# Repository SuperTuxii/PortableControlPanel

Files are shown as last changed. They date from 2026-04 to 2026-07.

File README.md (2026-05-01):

# PortableControlPanel
A control panel with a touchscreen, speaker and more that magnetically connects to a stand. The builtin battery allows it to be taken around and used wirelessly. Placing it on the stand will charge the battery through the magnetic connectors. It can be used to control lights or as a macro pad etc.

I made this since my light switch is quite far from my bed and it's always annoying when I'm in bed and have to turn off the lights. So I will probably put this in my bed for that purpose, but making it wireless still leaves me with the possibility to use it in even more ways in the future.

# Images
## Panel
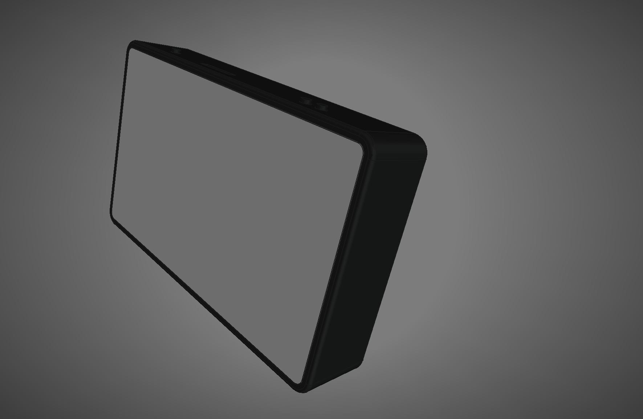
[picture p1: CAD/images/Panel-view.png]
View of the panel in CAD from the front

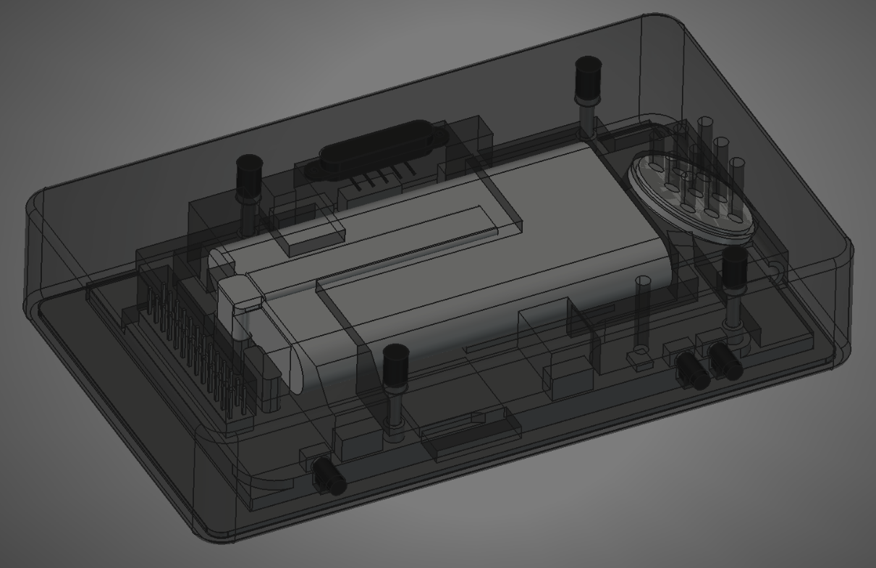
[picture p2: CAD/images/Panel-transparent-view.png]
View of the panel in CAD from the back with a transparent case

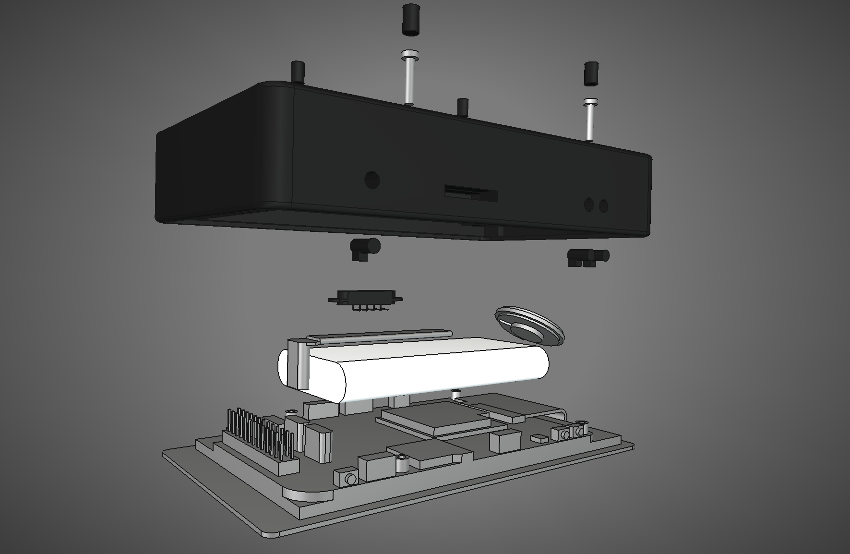
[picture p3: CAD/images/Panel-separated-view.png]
View of the separated panel in CAD

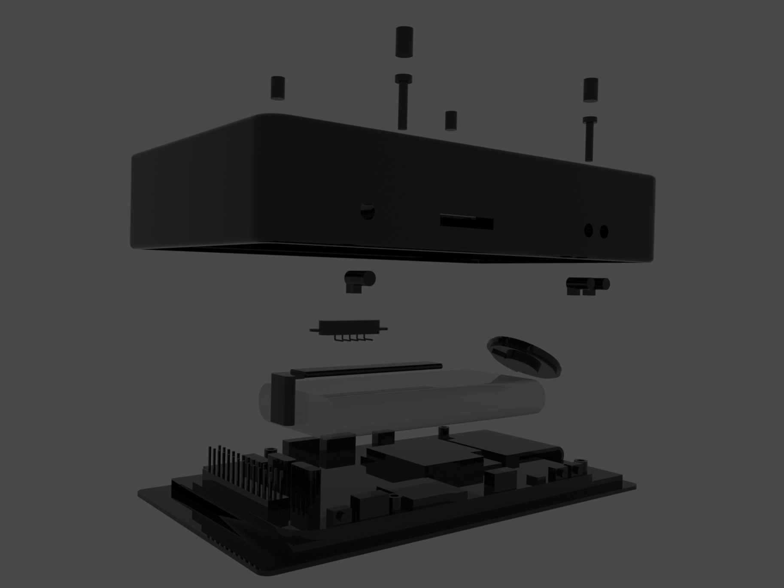
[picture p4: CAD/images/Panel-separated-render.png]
View of the separated panel as a render

## Stand
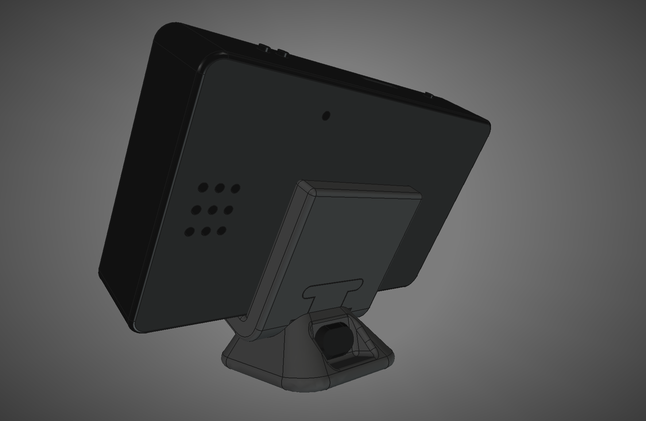
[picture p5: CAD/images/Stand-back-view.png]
View of the stand in CAD from the back

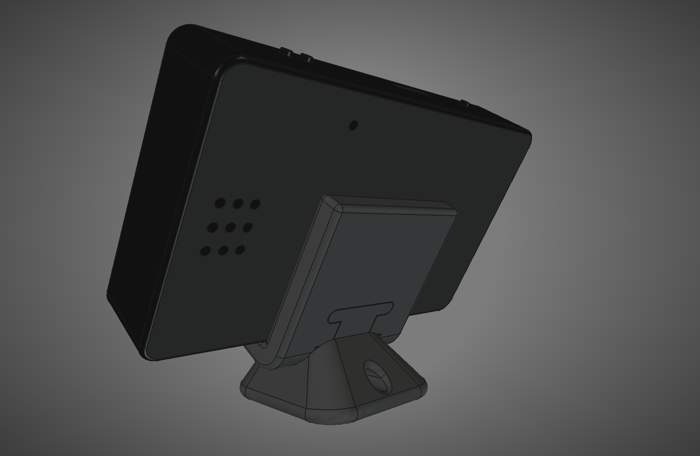
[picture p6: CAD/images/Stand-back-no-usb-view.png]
View of the stand without the usb port in CAD from the back

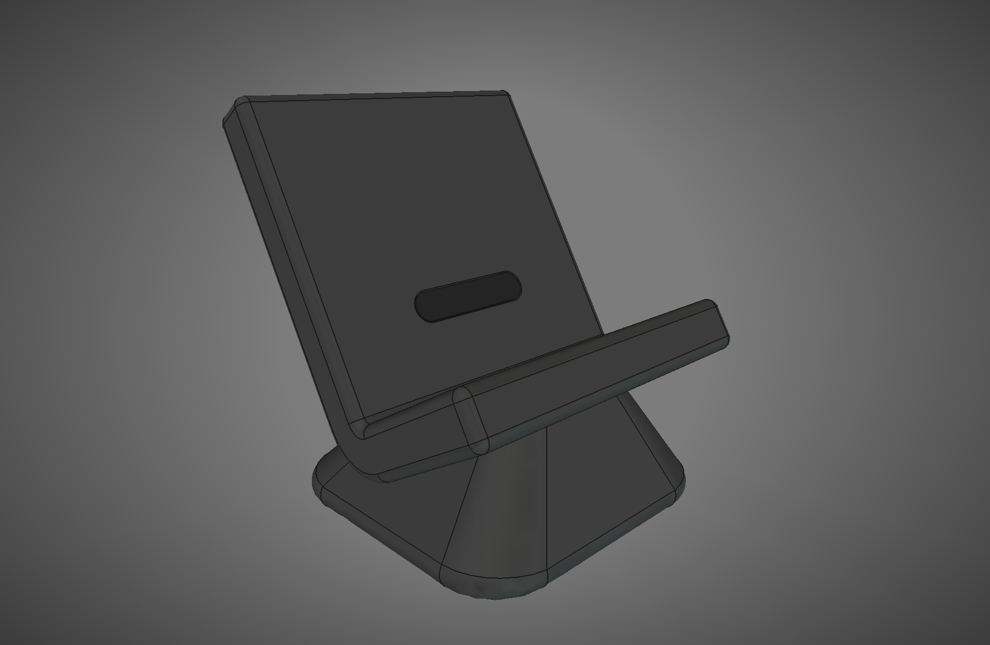
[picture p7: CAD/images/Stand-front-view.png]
View of the stand in CAD from the front

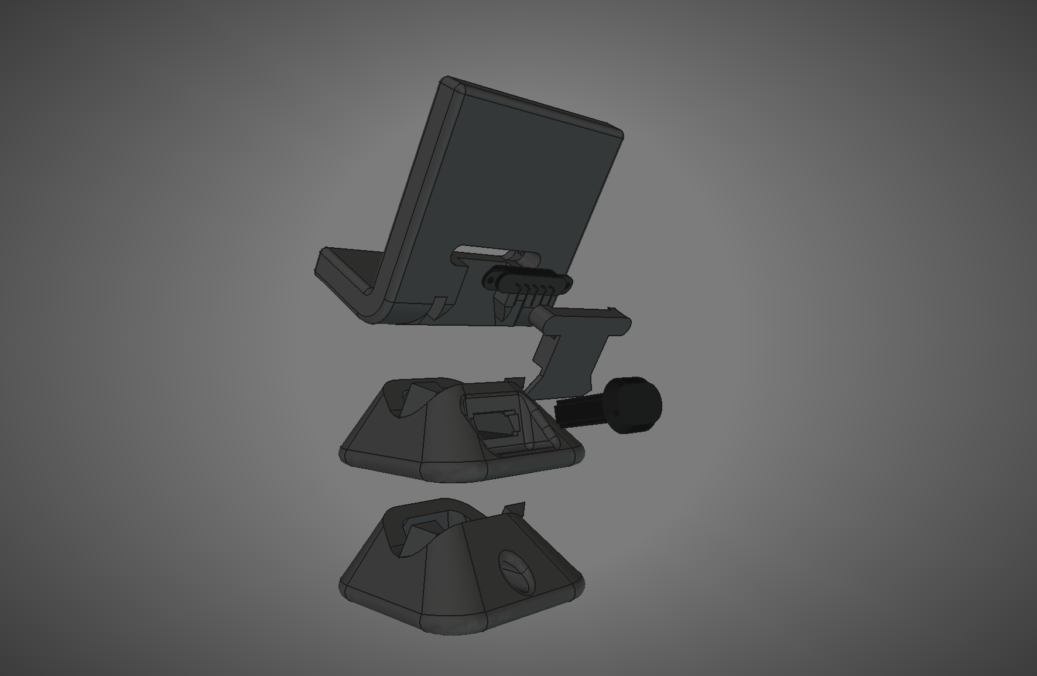
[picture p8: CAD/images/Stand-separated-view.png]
View of the separated stand in CAD


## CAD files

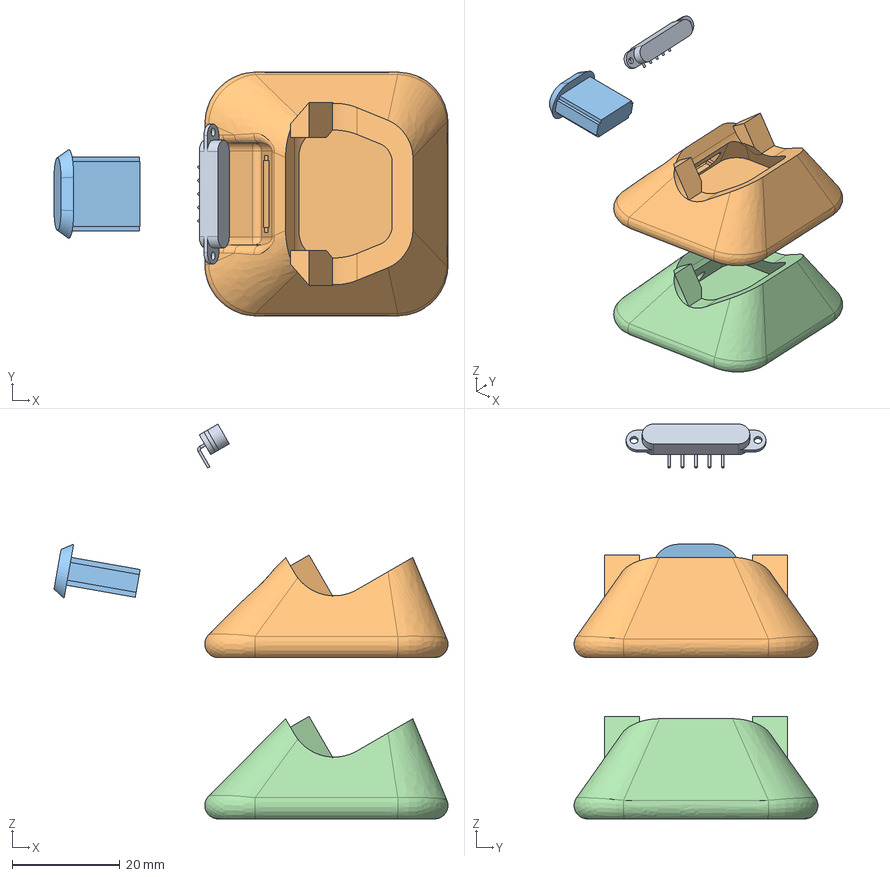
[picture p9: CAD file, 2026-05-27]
CAD/Stand-separated.FCStd
73.3 x 45.3 x 73.4 mm
MagnetConnector001
Base
UsbPort
BaseNoUsb

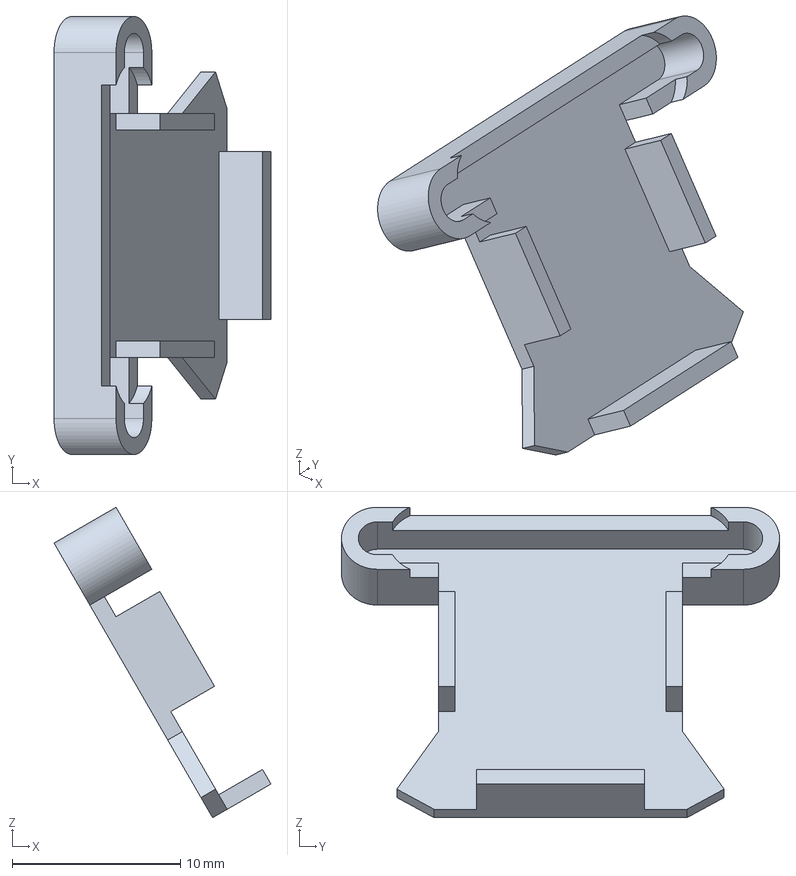
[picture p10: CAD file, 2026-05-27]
CAD/step_files/Stand-StandCover.step
12.9 x 26.0 x 18.4 mm

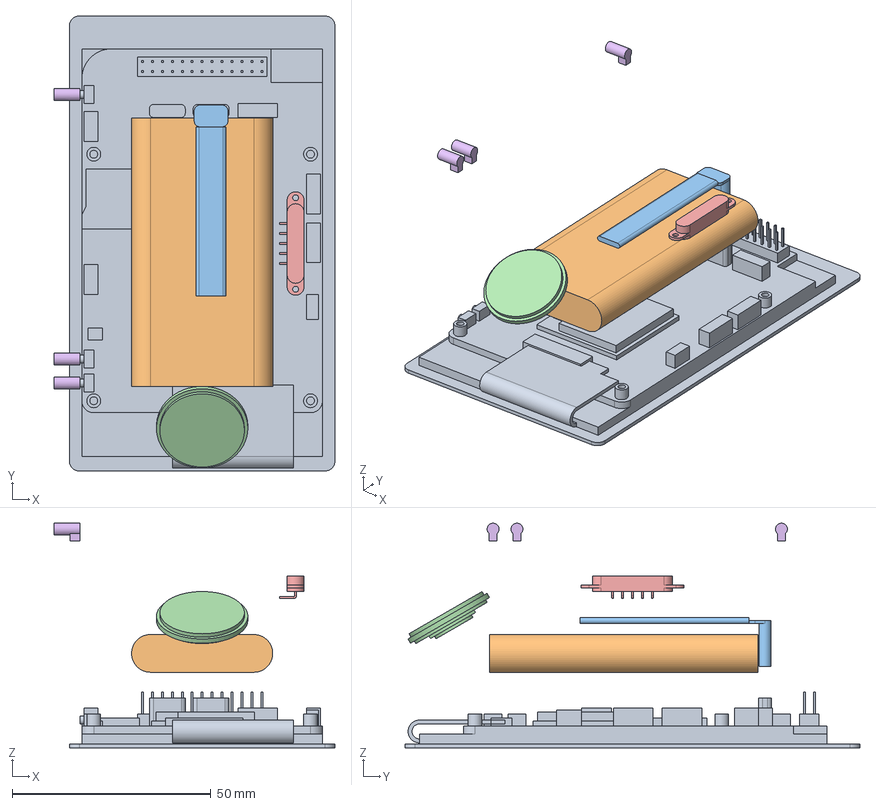
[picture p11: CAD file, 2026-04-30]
CAD/Panel-separated.FCStd
70.7 x 114.4 x 56.5 mm
DisplayModuleDevKit
Battery
UsbConnector
Speaker
MagnetConnector
ButtonPins

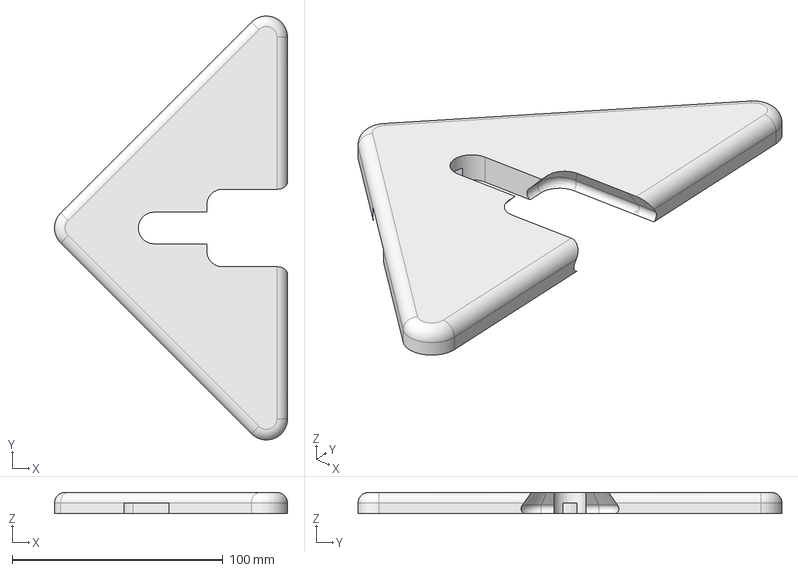
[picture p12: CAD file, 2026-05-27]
CAD/step_files/Stand-CornerBase.step
110.5 x 201.1 x 10.0 mm

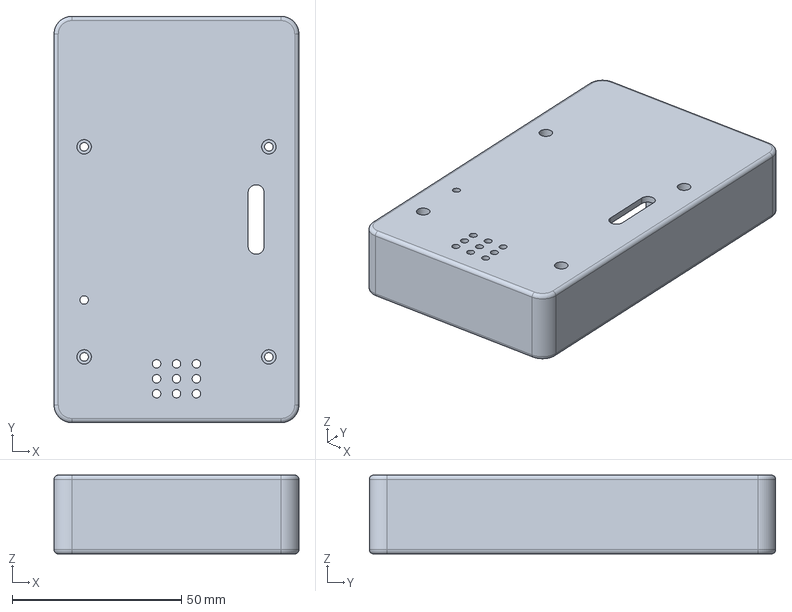
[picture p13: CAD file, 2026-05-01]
CAD/step_files/Panel-Case.step
72.3 x 119.9 x 23.2 mm

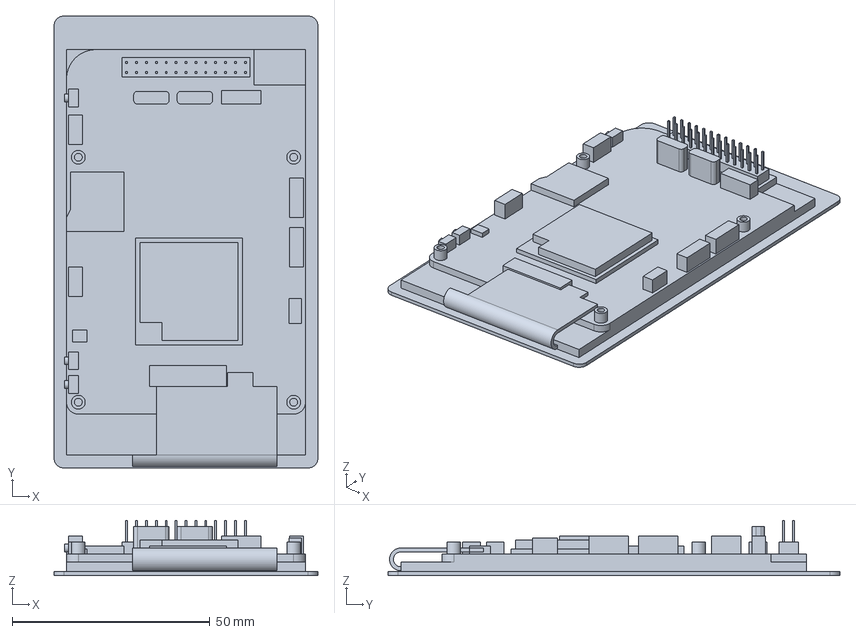
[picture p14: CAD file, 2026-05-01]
CAD/step_files/Panel-DisplayModuleDevKit.step
66.8 x 114.4 x 14.0 mm

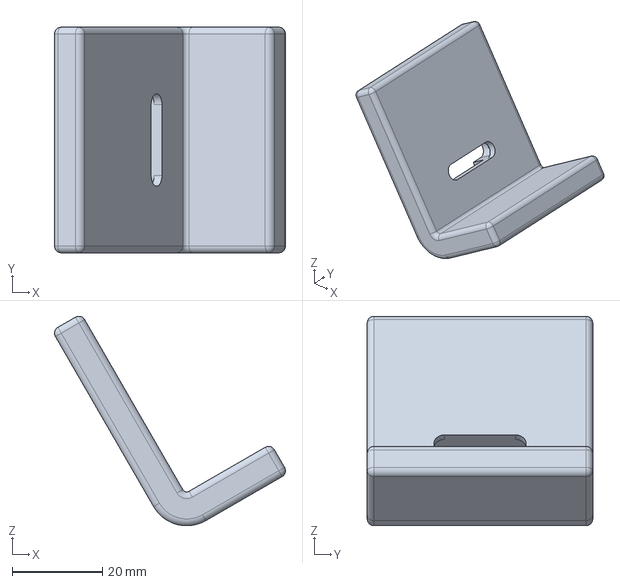
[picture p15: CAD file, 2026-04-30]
CAD/step_files/Stand-Stand.step
51.2 x 50.0 x 46.4 mm

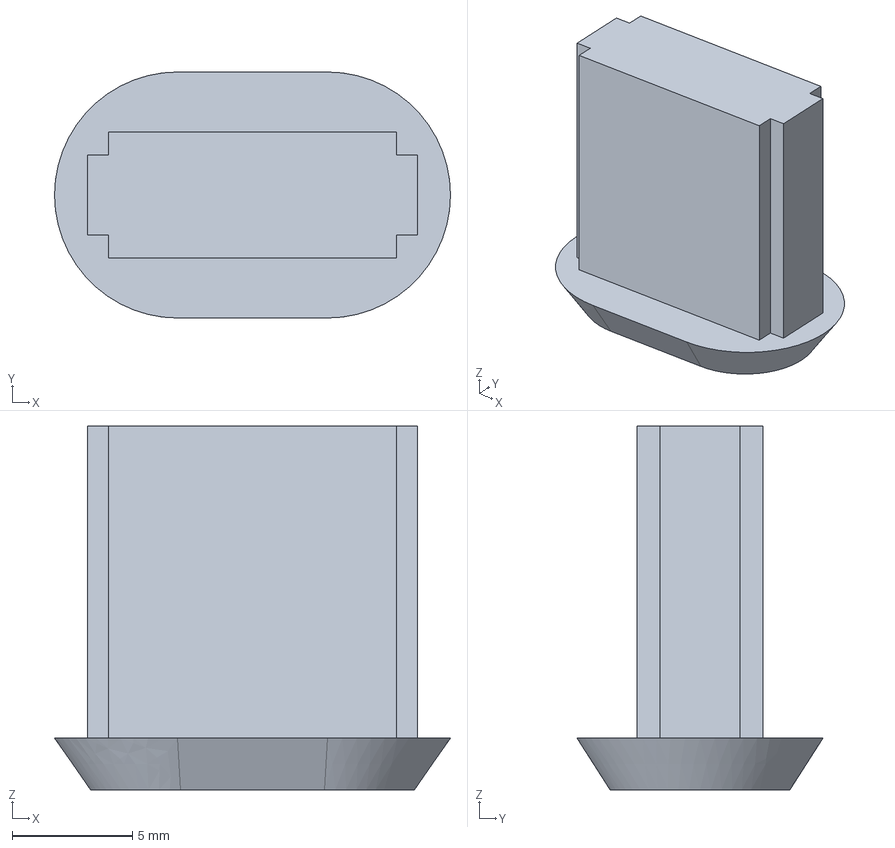
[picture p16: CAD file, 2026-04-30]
CAD/step_files/Stand-UsbPort.step
16.5 x 10.2 x 15.2 mm

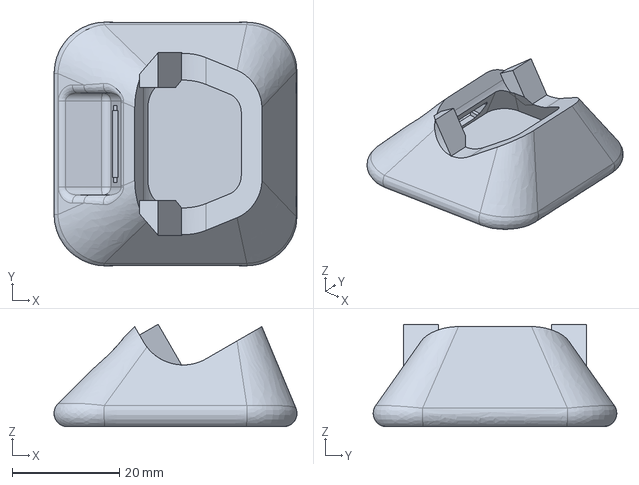
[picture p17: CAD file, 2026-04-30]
CAD/step_files/Stand-Base.step
45.2 x 45.3 x 19.1 mm

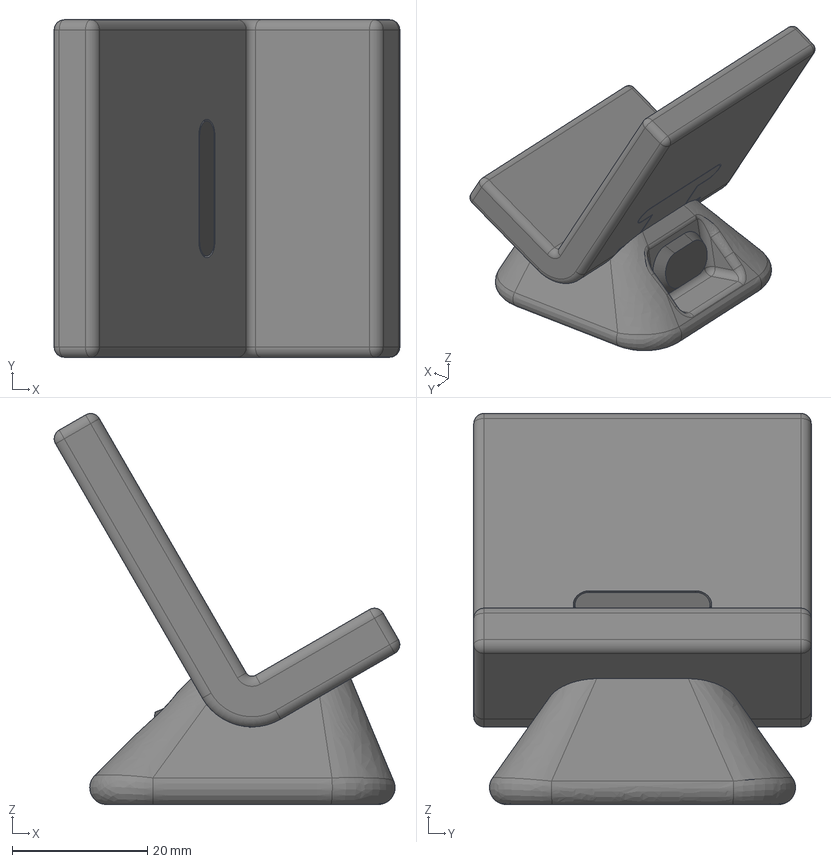
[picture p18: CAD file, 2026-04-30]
CAD/step_files/Stand.step
51.2 x 50.0 x 57.9 mm
Stand
Base
MagnetConnector001
UsbPort
StandCover

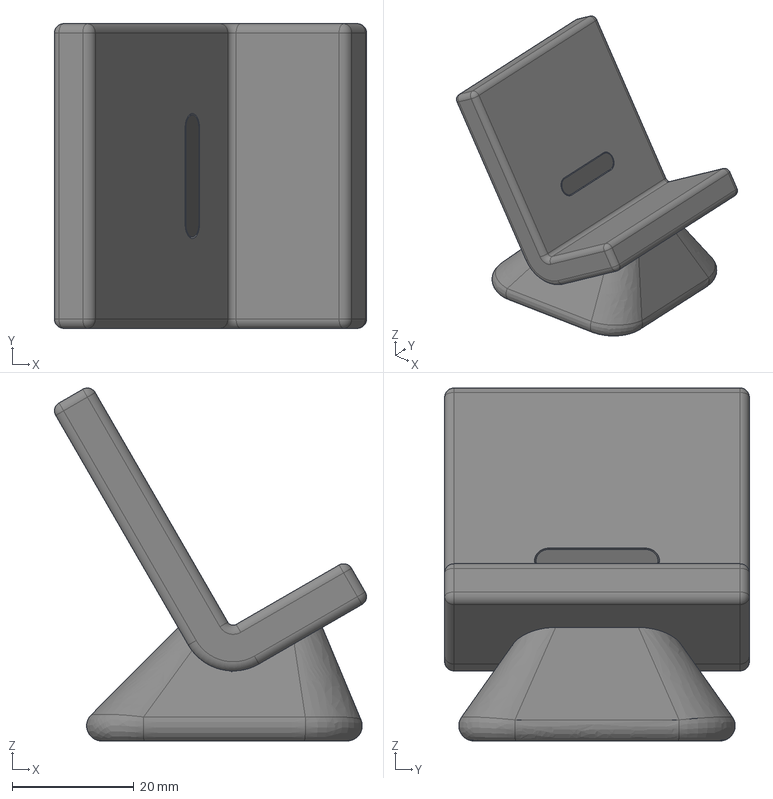
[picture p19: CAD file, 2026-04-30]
CAD/step_files/StandNoUsb.step
51.2 x 50.0 x 57.9 mm
Stand
MagnetConnector001
StandCover
BaseNoUsb

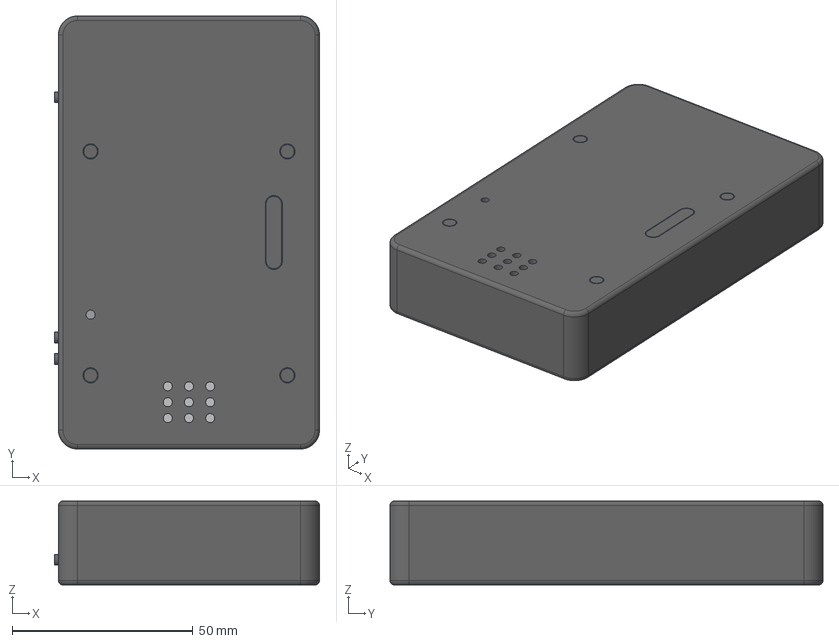
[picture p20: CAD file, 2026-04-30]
CAD/step_files/Panel.step
73.4 x 119.9 x 23.2 mm
ScrewCovers
Screws
ButtonPins
Case
MagnetConnector
Speaker
UsbConnector
Battery
DisplayModuleDevKit

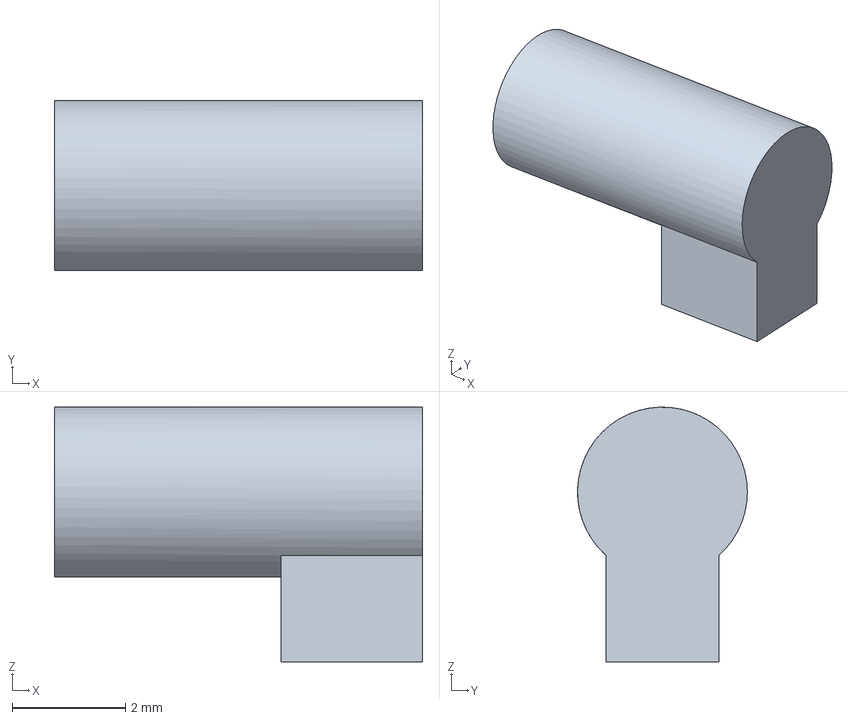
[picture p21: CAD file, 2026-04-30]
CAD/step_files/Panel-ButtonPin.step
6.50 x 3.00 x 4.50 mm

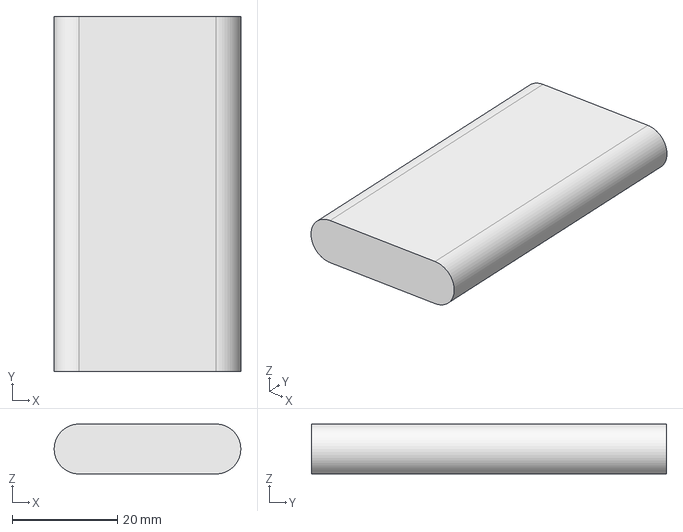
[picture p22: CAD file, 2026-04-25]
CAD/step_files/Panel-Battery.step
35.5 x 67.5 x 9.50 mm

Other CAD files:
CAD/step_files/Stand-BaseNoUsb.step
CAD/step_files/Panel-MagnetConnector.step
CAD/step_files/Panel-Speaker.step
CAD/step_files/Panel-UsbConnector.step
CAD/3d_printing/Panel-ButtonPin.3mf
CAD/3d_printing/Panel-Case.3mf
CAD/3d_printing/Panel-ScrewCover.3mf
CAD/3d_printing/Stand-Base.3mf
CAD/3d_printing/Stand-BaseNoUsb.3mf
CAD/3d_printing/Stand-CornerBase.3mf
CAD/3d_printing/Stand-Stand.3mf
CAD/3d_printing/Stand-StandCover.3mf
CAD/Panel.FCStd
CAD/Stand.FCStd
CAD/step_files/Panel-Screw.step
CAD/step_files/Panel-ScrewCover.step

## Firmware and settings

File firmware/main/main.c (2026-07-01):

/*
 * SPDX-FileCopyrightText: 2010-2022 Espressif Systems (Shanghai) CO LTD
 *
 * SPDX-License-Identifier: CC0-1.0
 */

#include <stdio.h>
#include <inttypes.h>

#include "sdkconfig.h"

#include "esp_log.h"
#include "tinyusb.h"
#include "tinyusb_default_config.h"
#include "tinyusb_cdc_acm.h"
#include "esp_lvgl_port.h"
#include "lvgl.h"
#include "lv_control_grid.h"
#include "display_driver.h"
#include "protocol.h"
#include "tinyusb_console.h"

#define ALIGN_UP(num, align)    (((num) + ((align) - 1)) & ~((align) - 1))
#define ALIGN_DOWN(num, align)  ((num) & ~((align) - 1))

static char *LVGL_TAG = "lvgl";

static esp_err_t lvgl_init() {
    ESP_LOGI(LVGL_TAG, "Initialize LVGL port");
    const lvgl_port_cfg_t lvgl_cfg = {
        .task_priority = LVGL_TASK_PRIORITY,
        .task_stack = LVGL_TASK_STACK_SIZE,
        .task_affinity = -1,
        .task_max_sleep_ms = LVGL_TASK_MAX_DELAY_MS,
        .task_stack_caps = MALLOC_CAP_SPIRAM,
        .timer_period_ms = LVGL_TICK_PERIOD_MS
    };
    ESP_ERROR_CHECK(lvgl_port_init(&lvgl_cfg));

    ESP_LOGI(LVGL_TAG, "Add MIPI DSI display");
    const lvgl_port_display_cfg_t display_cfg = {
        .io_handle = display_get_mipi_dpi_io(),
        .panel_handle = display_get_panel_handle(),
        .buffer_size = LCD_H_RES * LCD_V_RES,
        .double_buffer = true,
        .hres = LCD_H_RES,
        .vres = LCD_V_RES,
        .monochrome = false,
        .color_format = LV_COLOR_FORMAT_RGB565,
        .rotation = {
            .swap_xy = false,
            .mirror_x = false,
            .mirror_y = false,
        },
        .flags = {
            .buff_dma = true,
            .buff_spiram = true,
            .sw_rotate = true,
            .swap_bytes = false,
        }
    };
    const lvgl_port_display_dsi_cfg_t display_dsi_cfg = {
        //.flags.avoid_tearing = true   doesn't work for some reason. Me not know
    };
    lv_disp_t *display = lvgl_port_add_disp_dsi(&display_cfg, &display_dsi_cfg);
    lv_display_set_rotation(display, LV_DISPLAY_ROTATION_270);

    ESP_LOGI(LVGL_TAG, "Add touch");
    const lvgl_port_touch_cfg_t touch_cfg = {
        .disp = display,
        .handle = touch_get_tp_handle(),
    };
    lv_indev_t* touch_handle = lvgl_port_add_touch(&touch_cfg);

    ESP_LOGI(LVGL_TAG, "Aquire lvgl port lock");
    if (lvgl_port_lock(0)) {
        ESP_LOGI(LVGL_TAG, "Add LVGL widgets");
        lv_obj_set_style_bg_color(lv_screen_active(), lv_color_hex(0x000000), LV_PART_MAIN);
        lv_control_grid_create(lv_screen_active());
        lvgl_port_unlock();
    }
    return ESP_OK;
}

static void tinyusb_cdc_rx_callback(int itf, cdcacm_event_t *event) {
    if (itf != TINYUSB_PROTOCOL_PORT)
        return;
    tinyusbReadReady();
}

static esp_err_t tinyusb_init() {
    const tinyusb_config_t tusb_cfg = TINYUSB_DEFAULT_CONFIG();

    ESP_ERROR_CHECK(tinyusb_driver_install(&tusb_cfg));

    tinyusb_config_cdcacm_t acm_cfg = {
        .cdc_port = TINYUSB_PROTOCOL_PORT,
        .callback_rx = &tinyusb_cdc_rx_callback,
        .callback_rx_wanted_char = NULL,
        .callback_line_state_changed = NULL,
        .callback_line_coding_changed = NULL
    };
    ESP_ERROR_CHECK(tinyusb_cdcacm_init(&acm_cfg));
    ESP_ERROR_CHECK(tinyusb_console_init(TINYUSB_CDC_ACM_0));
    return ESP_OK;
}

void app_main(void) {
    // Initialize display and LVGL
    ESP_ERROR_CHECK(display_brightness_init());
    ESP_ERROR_CHECK(display_backlight_on());
    ESP_ERROR_CHECK(display_init());
    ESP_ERROR_CHECK(touch_init());
    ESP_ERROR_CHECK(lvgl_init());
    // Initialize TinyUSB (route console output to high speed usb)
    ESP_ERROR_CHECK(tinyusb_init());

    // printf("Hello world!\n");
    //
    // /* Print chip information */
    // esp_chip_info_t chip_info;
    // uint32_t flash_size;
    // esp_chip_info(&chip_info);
    // printf("This is %s chip with %d CPU core(s), %s%s%s%s, ",
    //        CONFIG_IDF_TARGET,
    //        chip_info.cores,
    //        (chip_info.features & CHIP_FEATURE_WIFI_BGN) ? "WiFi/" : "",
    //        (chip_info.features & CHIP_FEATURE_BT) ? "BT" : "",
    //        (chip_info.features & CHIP_FEATURE_BLE) ? "BLE" : "",
    //        (chip_info.features & CHIP_FEATURE_IEEE802154) ? ", 802.15.4 (Zigbee/Thread)" : "");
    //
    // unsigned major_rev = chip_info.revision / 100;
    // unsigned minor_rev = chip_info.revision % 100;
    // printf("silicon revision v%d.%d, ", major_rev, minor_rev);
    // if(esp_flash_get_size(NULL, &flash_size) != ESP_OK) {
    //     printf("Get flash size failed");
    //     return;
    // }
    //
    // printf("%" PRIu32 "MB %s flash\n", flash_size / (uint32_t)(1024 * 1024),
    //        (chip_info.features & CHIP_FEATURE_EMB_FLASH) ? "embedded" : "external");
    //
    // printf("Minimum free heap size: %" PRIu32 " bytes\n", esp_get_minimum_free_heap_size());
    //
    // for (int i = 10; i >= 0; i--) {
    //     printf("Restarting in %d seconds...\n", i);
    //     vTaskDelay(1000 / portTICK_PERIOD_MS);
    // }
    // printf("Restarting now.\n");
    // fflush(stdout);
    // display_backlight_off();
    // esp_restart();
}

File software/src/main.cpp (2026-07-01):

#include <QGuiApplication>
#include <QQmlApplicationEngine>

int main(int argc, char *argv[])
{
    QGuiApplication app(argc, argv);
    QGuiApplication::setOrganizationName("PortableControlPanel");
    QGuiApplication::setOrganizationDomain("https://github.com/SuperTuxii/PortableControlPanel");
    QGuiApplication::setApplicationName("ControlPanelSoftware");

    QQmlApplicationEngine engine;
    QObject::connect(
        &engine,
        &QQmlApplicationEngine::objectCreationFailed,
        &app,
        []() { QCoreApplication::exit(-1); },
        Qt::QueuedConnection);
    engine.addImportPath(":/");
    engine.loadFromModule("ControlPanelSoftware", "Main");

    return app.exec();
}

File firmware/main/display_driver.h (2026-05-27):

#ifndef CONTROL_PANEL_FIRMWARE_DISPLAY_DRIVER_H
#define CONTROL_PANEL_FIRMWARE_DISPLAY_DRIVER_H
#include "esp_lcd_st7701.h"
#include "esp_lcd_touch_gt911.h"
#include "esp_err.h"

#define CONFIG_USE_DMA2D_COPY_FRAME     1

#define MIPI_DSI_PHY_PWR_LDO_CHAN       3
#define MIPI_DSI_PHY_PWR_LDO_VOLTAGE_MV 2500
#define MIPI_DSI_LANE_NUM               2
#define MIPI_DSI_LANE_BITRATE_MBPS      500
#define MIPI_DSI_DPI_CLK_MHZ            34
#define LCD_H_RES                       480
#define LCD_V_RES                       800
#define LCD_HSYNC                       12
#define LCD_HBP                         42
#define LCD_HFP                         42
#define LCD_VSYNC                       2
#define LCD_VBP                         8
#define LCD_VFP                         166

#define TOUCH_I2C_NUM                   I2C_NUM_1
#define TOUCH_I2C_SDA                   GPIO_NUM_7
#define TOUCH_I2C_SCL                   GPIO_NUM_8
#define TOUCH_RST                       GPIO_NUM_NC
#define TOUCH_INT                       GPIO_NUM_NC

#define LCD_BIT_PER_PIXEL               16
#define LCD_RST                         GPIO_NUM_5
#define LCD_BACKLIGHT                   GPIO_NUM_23
#define LCD_LEDC_CH                     LEDC_CHANNEL_0

#define ST7701_480_800_PANEL_DPI_CONFIG(color_format)  \
    {                                                       \
        .virtual_channel = 0,                               \
        .dpi_clk_src = MIPI_DSI_DPI_CLK_SRC_DEFAULT,        \
        .dpi_clock_freq_mhz = MIPI_DSI_DPI_CLK_MHZ,         \
        .in_color_format = color_format,                    \
        .num_fbs = 1,                                       \
        .video_timing = {                                   \
            .h_size = LCD_H_RES,                            \
            .v_size = LCD_V_RES,                            \
            .hsync_pulse_width = LCD_HSYNC,                 \
            .hsync_back_porch = LCD_HFP,                    \
            .hsync_front_porch = LCD_HFP,                   \
            .vsync_pulse_width = LCD_VSYNC,                 \
            .vsync_back_porch = LCD_VBP,                    \
            .vsync_front_porch = LCD_VFP,                   \
        },                                                  \
    }

#define LVGL_DRAW_BUF_LINES             LCD_V_RES
#define LVGL_TICK_PERIOD_MS             2
#define LVGL_TASK_STACK_SIZE            (6 * 1024)
#define LVGL_TASK_PRIORITY              2
#define LVGL_TASK_MAX_DELAY_MS          500
#define LVGL_TASK_MIN_DELAY_MS          (1000 / CONFIG_FREERTOS_HZ)

static const st7701_lcd_init_cmd_t vendor_specific_init[] = {
    {0xFF, (uint8_t []){0x77,0x01,0x00,0x00,0x13},5,0},
    {0xEF, (uint8_t []){0x08}, 1, 0},
    {0xFF, (uint8_t []){0x77,0x01,0x00,0x00,0x10},5,0},
    {0xC0, (uint8_t []){0x63, 0x00}, 2, 0},
    {0xC1, (uint8_t []){0x0D, 0x02}, 2, 0},
    {0xC2, (uint8_t []){0x10, 0x08}, 2, 0},
    {0xCC, (uint8_t []){0x10}, 1, 0},

    {0xB0, (uint8_t []){0x80, 0x09, 0x53, 0x0C, 0xD0, 0x07, 0x0C, 0x09, 0x09, 0x28, 0x06, 0xD4, 0x13, 0x69, 0x2B, 0x71}, 16, 0},
    {0xB1, (uint8_t []){0x80, 0x94, 0x5A, 0x10, 0xD3, 0x06, 0x0A, 0x08, 0x08, 0x25, 0x03, 0xD3, 0x12, 0x66, 0x6A, 0x0D}, 16, 0},
    {0xFF, (uint8_t []){0x77, 0x01, 0x00, 0x00, 0x11}, 5, 0},

    {0xB0, (uint8_t []){0x5D}, 1, 0},
    {0xB1, (uint8_t []){0x58}, 1, 0},
    {0xB2, (uint8_t []){0x87}, 1, 0},
    {0xB3, (uint8_t []){0x80}, 1, 0},
    {0xB5, (uint8_t []){0x4E}, 1, 0},
    {0xB7, (uint8_t []){0x85}, 1, 0},
    {0xB8, (uint8_t []){0x21}, 1, 0},
    {0xB9, (uint8_t []){0x10, 0x1F}, 2, 0},
    {0xBB, (uint8_t []){0x03}, 1,0},
    {0xBC, (uint8_t []){0x00}, 1,0},

    {0xC1, (uint8_t []){0x78}, 1, 0},
    {0xC2, (uint8_t []){0x78}, 1, 0},
    {0xD0, (uint8_t []){0x88}, 1, 0},

    {0xE0, (uint8_t []){0x00, 0x3A, 0x02}, 3, 0},
    {0xE1, (uint8_t []){0x04, 0xA0, 0x00, 0xA0, 0x05,0xA0, 0x00, 0xA0, 0x00, 0x40, 0x40}, 11, 0},
    {0xE2, (uint8_t []){0x30, 0x00, 0x40, 0x40, 0x32, 0xA0, 0x00, 0xA0, 0x00, 0xA0, 0x00, 0xA0, 0x00}, 13, 0},
    {0xE3, (uint8_t []){0x00, 0x00, 0x33, 0x33}, 4, 0},
    {0xE4, (uint8_t []){0x44, 0x44}, 2, 0},
    {0xE5, (uint8_t []){0x09, 0x2E, 0xA0, 0xA0, 0x0B, 0x30, 0xA0, 0xA0, 0x05, 0x2A, 0xA0, 0xA0, 0x07, 0x2C, 0xA0, 0xA0}, 16, 0},
    {0xE6, (uint8_t []){0x00, 0x00, 0x33, 0x33}, 4, 0},
    {0xE7, (uint8_t []){0x44, 0x44}, 2, 0},
    {0xE8, (uint8_t []){0x08, 0x2D, 0xA0, 0xA0, 0x0A, 0x2F, 0xA0, 0xA0, 0x04, 0x29, 0xA0, 0xA0, 0x06, 0x2B, 0xA0, 0xA0}, 16, 0},

    {0xEB, (uint8_t []){0x00, 0x00, 0x4E, 0x4E, 0x00, 0x00, 0x00}, 7, 0},
    {0xEC, (uint8_t []){0x08, 0x01}, 2, 0},

    {0xED, (uint8_t []){0xB0, 0x2B, 0x98, 0xA4, 0x56, 0x7F, 0xFF, 0xFF, 0xFF, 0xFF, 0xF7, 0x65, 0x4A, 0x89, 0xB2, 0x0B}, 16, 0},
    {0xEF, (uint8_t []){0x08, 0x08, 0x08, 0x45, 0x3F, 0x54}, 6, 0},
    {0xFF, (uint8_t []){0x77, 0x01, 0x00, 0x00, 0x00}, 5, 0},

    // {0x3A, (uint8_t []){0x66}, 1, 0},
    {0x11, (uint8_t []){0x00}, 1, 120},
    {0x29, (uint8_t []){0x00}, 1, 20},
};

esp_err_t display_brightness_init();
esp_err_t display_init();
esp_err_t touch_init();

esp_err_t display_brightness_set(int brightness);
esp_err_t display_backlight_off();
esp_err_t display_backlight_on();

esp_lcd_panel_io_handle_t display_get_mipi_dpi_io();
esp_lcd_panel_handle_t display_get_panel_handle();
esp_lcd_touch_handle_t touch_get_tp_handle();

#endif //CONTROL_PANEL_FIRMWARE_DISPLAY_DRIVER_H

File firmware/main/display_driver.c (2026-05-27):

#include "freertos/FreeRTOS.h"
#include "driver/ledc.h"
#include "driver/i2c_master.h"
#include "esp_ldo_regulator.h"
#include "esp_lcd_panel_io.h"
#include "esp_lcd_panel_ops.h"
#include "esp_lcd_mipi_dsi.h"
#include "esp_lcd_st7701.h"
#include "esp_lcd_touch_gt911.h"
#include "esp_log.h"
#include "display_driver.h"

static const char *BACKLIGHT_TAG = "st7701_backlight";
static const char *DISPLAY_TAG = "st7701_display";
static const char *TOUCH_TAG = "gt911_touch";

static esp_lcd_panel_io_handle_t mipi_dbi_io = NULL;
static esp_lcd_panel_handle_t panel_handle = NULL;
static esp_lcd_touch_handle_t tp_handle = NULL;

esp_err_t display_brightness_init() {
    ESP_LOGI(BACKLIGHT_TAG, "Initialize LCD backlight LED Control");
    const ledc_channel_config_t LCD_backlight_channel = {
        .gpio_num = LCD_BACKLIGHT,
        .speed_mode = LEDC_LOW_SPEED_MODE,
        .channel = LCD_LEDC_CH,
        .timer_sel = 1,
        .duty = 0,
        .hpoint = 0
    };
    const ledc_timer_config_t LCD_backlight_timer = {
        .speed_mode = LEDC_LOW_SPEED_MODE,
        .duty_resolution = LEDC_TIMER_10_BIT,
        .timer_num = 1,
        .freq_hz = 5000,
        .clk_cfg = LEDC_AUTO_CLK
    };

    ESP_ERROR_CHECK(ledc_timer_config(&LCD_backlight_timer));
    ESP_ERROR_CHECK(ledc_channel_config(&LCD_backlight_channel));
    return ESP_OK;
}

esp_err_t display_init() {
    ESP_LOGI(DISPLAY_TAG, "MIPI DSI PHY Powered on");
    static esp_ldo_channel_handle_t ldo_mipi_phy = NULL;

    esp_ldo_channel_config_t ldo_mipi_phy_config = {
        .chan_id = MIPI_DSI_PHY_PWR_LDO_CHAN,
        .voltage_mv = MIPI_DSI_PHY_PWR_LDO_VOLTAGE_MV,
    };
    ESP_ERROR_CHECK(esp_ldo_acquire_channel(&ldo_mipi_phy_config, &ldo_mipi_phy));

    ESP_LOGI(DISPLAY_TAG, "Initialize MIPI DSI bus");
    static esp_lcd_dsi_bus_handle_t mipi_dsi_bus = NULL;
    esp_lcd_dsi_bus_config_t bus_config = {
        .bus_id = 0,
        .num_data_lanes = MIPI_DSI_LANE_NUM,
        .phy_clk_src = MIPI_DSI_PHY_CLK_SRC_DEFAULT,
        .lane_bit_rate_mbps = MIPI_DSI_LANE_BITRATE_MBPS,
    };
    ESP_ERROR_CHECK(esp_lcd_new_dsi_bus(&bus_config, &mipi_dsi_bus));

    ESP_LOGI(DISPLAY_TAG, "Install panel IO");
    esp_lcd_dbi_io_config_t dbi_config = ST7701_PANEL_IO_DBI_CONFIG();
    ESP_ERROR_CHECK(esp_lcd_new_panel_io_dbi(mipi_dsi_bus, &dbi_config, &mipi_dbi_io));

    ESP_LOGI(DISPLAY_TAG, "Install LCD driver of st7701");
    esp_lcd_dpi_panel_config_t dpi_config = ST7701_480_800_PANEL_DPI_CONFIG(LCD_COLOR_FMT_RGB565);
    st7701_vendor_config_t vendor_config = {
        .init_cmds = vendor_specific_init,
        .init_cmds_size = sizeof(vendor_specific_init) / sizeof(st7701_lcd_init_cmd_t),
        .mipi_config = {
            .dsi_bus = mipi_dsi_bus,
            .dpi_config = &dpi_config,
        },
        .flags = {
            .use_mipi_interface = true,
        },
    };
    const esp_lcd_panel_dev_config_t panel_config = {
        .reset_gpio_num = LCD_RST,
        .rgb_ele_order = LCD_RGB_ELEMENT_ORDER_RGB,
        .bits_per_pixel = LCD_BIT_PER_PIXEL,
        .vendor_config = &vendor_config,
    };
    ESP_ERROR_CHECK(esp_lcd_new_panel_st7701(mipi_dbi_io, &panel_config, &panel_handle));
#if CONFIG_USE_DMA2D_COPY_FRAME
    ESP_ERROR_CHECK(esp_lcd_dpi_panel_enable_dma2d(panel_handle));
    ESP_LOGI(DISPLAY_TAG, "DPI panel added DMA2D draw bitmap hook");
#endif
    ESP_ERROR_CHECK(esp_lcd_panel_reset(panel_handle));
    ESP_ERROR_CHECK(esp_lcd_panel_init(panel_handle));
    ESP_ERROR_CHECK(esp_lcd_panel_disp_on_off(panel_handle, true));
    return ESP_OK;
}

esp_err_t touch_init() {
    ESP_LOGI(TOUCH_TAG, "Initialize I2C bus");
    i2c_master_bus_handle_t i2c_handle = NULL;
    i2c_master_bus_config_t i2c_bus_conf = {
        .clk_source = I2C_CLK_SRC_DEFAULT,
        .sda_io_num = TOUCH_I2C_SDA,
        .scl_io_num = TOUCH_I2C_SCL,
        .i2c_port = TOUCH_I2C_NUM,
    };
    ESP_ERROR_CHECK(i2c_new_master_bus(&i2c_bus_conf, &i2c_handle));

    ESP_LOGI(TOUCH_TAG, "Install panel IO");
    esp_lcd_panel_io_handle_t tp_io_handle = NULL;
    esp_lcd_panel_io_i2c_config_t tp_io_config = ESP_LCD_TOUCH_IO_I2C_GT911_CONFIG();
    tp_io_config.scl_speed_hz = 100000;
    ESP_ERROR_CHECK(esp_lcd_new_panel_io_i2c(i2c_handle, &tp_io_config, &tp_io_handle));

    ESP_LOGI(TOUCH_TAG, "Install LCD touch driver of gt911");
    const esp_lcd_touch_config_t tp_cfg = {
        .x_max = LCD_H_RES,
        .y_max = LCD_V_RES,
        .rst_gpio_num = TOUCH_RST,
        .int_gpio_num = TOUCH_INT,
        .levels = {
            .reset = 0,
            .interrupt = 0,
        },
        .flags = {
            .swap_xy = 0,
            .mirror_x = 0,
            .mirror_y = 0,
        },
    };
    ESP_ERROR_CHECK(esp_lcd_touch_new_i2c_gt911(tp_io_handle, &tp_cfg, &tp_handle));
    return ESP_OK;
}


esp_err_t display_brightness_set(int brightness) {
    if (brightness > 1023)
        brightness = 1023;
    if (brightness < 0)
        brightness = 0;
    ESP_LOGI(BACKLIGHT_TAG, "Setting LCD backlight: %d/1023", brightness);
    ESP_ERROR_CHECK(ledc_set_duty(LEDC_LOW_SPEED_MODE, LCD_LEDC_CH, brightness));
    ESP_ERROR_CHECK(ledc_update_duty(LEDC_LOW_SPEED_MODE, LCD_LEDC_CH));
    return ESP_OK;
}

esp_err_t display_backlight_off() {
    return display_brightness_set(0);
}

esp_err_t display_backlight_on() {
    return display_brightness_set(1023);
}

esp_lcd_panel_io_handle_t display_get_mipi_dpi_io() {
    return mipi_dbi_io;
}
esp_lcd_panel_handle_t display_get_panel_handle() {
    return panel_handle;
}
esp_lcd_touch_handle_t touch_get_tp_handle() {
    return tp_handle;
}

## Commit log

2026-04-19 CAD: Create a model of the devkit
    [Panel.FCStd]
2026-04-22 Finish the 3d model for the panel
    Finish everything there is to model for the panel.
    Like the hardware parts, the case, etc.
    [Panel-ButtonPin.3mf, Panel-Case.3mf, Panel.FCStd]
2026-04-23 Edit README and add Images
    Edit README to include a better description and add a few images
    including a rendered one and one with separated parts.
    [Panel-ButtonPin.step, Panel-Case.step, Panel-separated.FCStd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]
2026-04-25 Restructure CAD Folder
    [Panel-ButtonPin.3mf, Panel-ButtonPin.step, Panel-Case.3mf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]
2026-04-25 Add step files for everything from panel and start creating a 3d model for the stand
    [Panel-Battery.step, Panel-DisplayModuleDevKit.step, Panel-MagnetConnector.step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]
2026-04-29 Finish 3d model for the stand and add images of it to the README
    [Stand-Base.3mf, Stand-BaseNoUsb.3mf, Stand-Stand.3mf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]
2026-04-30 Add screws to panel and update the images accordingly
    [Panel-separated.FCStd, Panel.FCStd]
2026-04-30 Update Panel step files and 3d printing files
    [Panel-ButtonPin.3mf, Panel-ButtonPin.step, Panel-Case.3mf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]
2026-04-30 Add a cover to the back of the stand to cover the up the cables that will run there
    [Stand-separated.FCStd, Stand.FCStd]
2026-04-30 Update step and 3mf files for the stand because of changes from the previous commit also add gitignore
    [Stand-Base.step, Stand-BaseNoUsb.step, Stand-Stand.3mf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]
2026-05-01 Some hopefully last changes/improvements to the panel model
    [Panel-Case.3mf, Panel-Case.step, Panel-DisplayModuleDevKit.step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]
2026-05-01 Add an image of the panel from the back with a transparent case to the README
2026-05-27 Some last changes to the stand 3d models
    Add a new model (CornerBase) for giving the stand more stability (Needed
    for it to be stable when it is on the side of my bed later).
    Also slightly change the StandCover since the design before didn't fit
    and had to be cut to fit into the base. Now it should be fine. Also
    adjust the seperated picture to match this change.
    [Panel-Case.3mf, Panel-ScrewCover.3mf, Stand-CornerBase.3mf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]
2026-05-27 Initial Firmware and Software Commit
    This includes the firmware and software code that I have been working on
    for a couple of weeks now. I am to lazy to split this up into several
    commits with more detail so here is the gist of what works:
    The Protocol which is defined in the Protocol Specification is
    completely implemented for the current state in the firmware.
    There are 2 util scripts in the firmware folder for trying out the
    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
2026-07-01 Commit Current Development State
    Commit any of the changes made since the newest commit on the main
    branch. I am to lazy right now to make proper commits to the main
    branch, but I want to push my changes to the remote. Therefore, this
    commit will probably be split up in the future and should not be merged
    into the main branch at this point.
